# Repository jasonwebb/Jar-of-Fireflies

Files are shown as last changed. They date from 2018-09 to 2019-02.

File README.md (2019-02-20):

---
WARNING: This project is currently being prototyped! Ping me if you'd like to build one and want to know the current status.
---

# Jar of Fireflies

Mason jar outfitted with LEDs and a small microcontroller programmed to mimic the behavior of fireflies caught on a warm summer night. A gentle tap of a button catches the attention of a lights, startling them and causing them to rapidly flash for a moment before returning to their blissful natural state.

An external sensor interface enables more complex interactions using both analog and digital sensors for properties like temperature, sound, light, distance/proximity, movement, tilt, biometrics, and much more.

This is a modernized reinvention of the classic ["Jar of fireflies"](http://www.instructables.com/id/Jar-of-Fireflies/) project by Keso using the Arduino framework and the ATTiny85 microcontroller.

## Features
* ATTiny85 microcontroller programmed with Arduino using the [HLT bootloader](http://hlt.media.mit.edu/?p=1695), mounted in a DIP IC socket for easy removal and replacement.
* Six charlieplexed through-hole LEDs, with the option to use SMD LEDs with fancy soldering.
* Large plated hole pairs for alligator clips so multiple jars can be daisy-chained to a single power source.
* Tactile button to trigger an animation sequence ("dance mode").
* 3-pin interface for external sensors (both analog and digital) to enable more complex interactions.
* 2x3 pin ICSP interface for easier reprogramming.
* Multiple power input options including:
  * 3.5mm center-positive barrel jack for common wall supplies.
  * 2-pin JST-PH jack for battery packs.

## License
This work is licensed under the [Creative Commons BY-NC-SA (Attribution - NonCommercial - ShareAlike) 4.0 International License](http://creativecommons.org/licenses/by-nc-sa/4.0/).



This means that you are completely free to use and modify any of these files for personal and educational use (with a shout-out 🙂), but manufacturing, selling and marketing this project to mass markets for your own profit is prohibited. If this is something that you are interested in doing, please contact me about setting up a partnership!

This license is chosen mainly in an effort, however naive, to discourage low-quality "knock offs" from flooding the market, which can lead to frustration and lack of trust in consumers caused by poor documentation, support, and quality assurance - a concern that tends to be unique to open-source hardware.

I expressly and strongly approve of use of this project for conference badges/swag, soldering workshops, art projects, and other small-scale community and creative-oriented applications. Such applications are what motivate me to share these source files in the first place!

## Designs

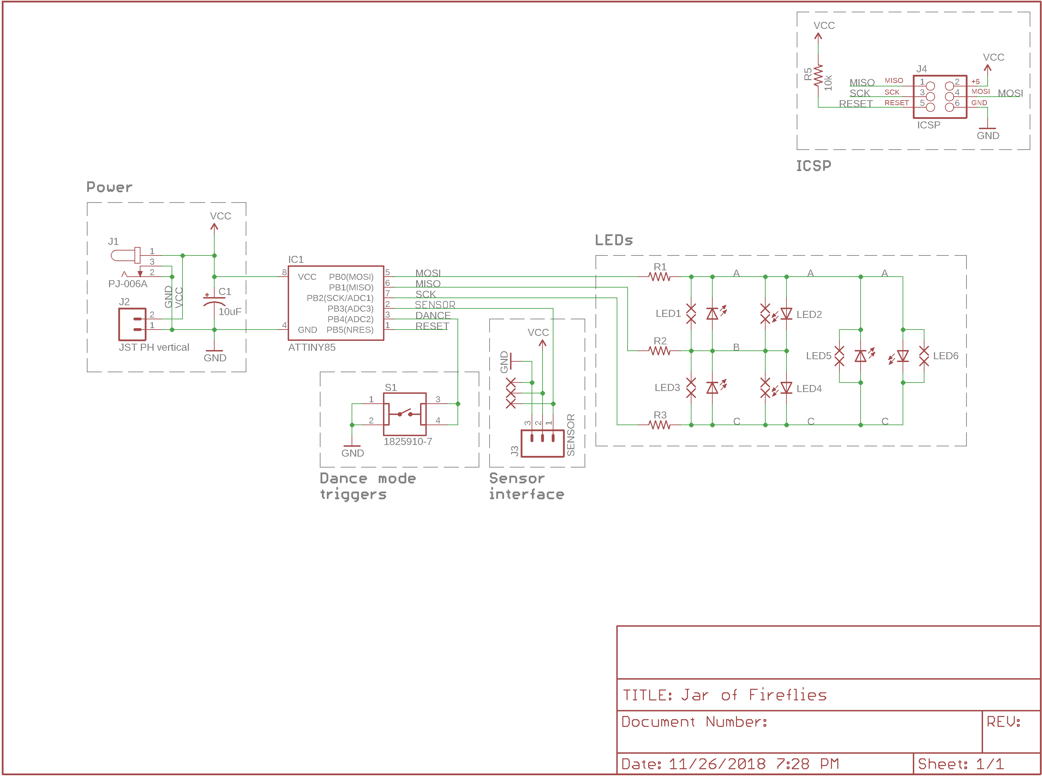
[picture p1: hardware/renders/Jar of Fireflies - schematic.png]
Schematic


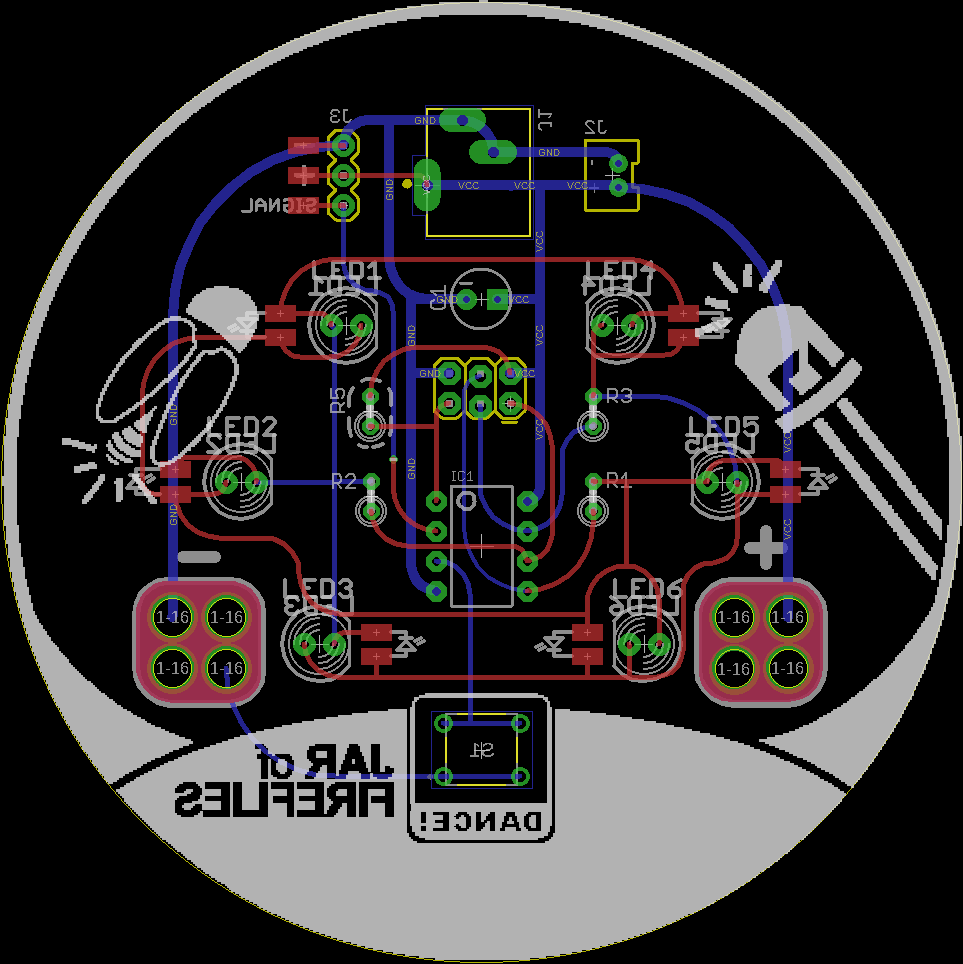
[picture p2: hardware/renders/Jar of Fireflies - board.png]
PCB layout


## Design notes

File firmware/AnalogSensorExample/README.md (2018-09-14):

Examples of sensors:
- [Proximity/distance](https://www.sparkfun.com/categories/84) - thinking of IR rangefinders, but could also work for ultrasonic rangefinders
- [Temperature](https://www.sparkfun.com/categories/82)
- Tilt using mechanical sensor or accelerometer for hands-on manipulation
- [Sound](https://www.sparkfun.com/categories/186)
- [Flex or force](https://www.sparkfun.com/categories/143)
- Biometrics
  - [Muscle activity](https://www.sparkfun.com/products/13723)
- Environmental
  - [Soil moisture](https://www.sparkfun.com/products/13637)
  - [pH level](https://www.sparkfun.com/products/10972)
  - Various gas and chemical sensors ([LPG](https://www.sparkfun.com/products/9405), [particles](https://www.sparkfun.com/products/14045), [dissolved oxygen](https://www.sparkfun.com/products/11194), [more](https://www.sparkfun.com/categories/146)).

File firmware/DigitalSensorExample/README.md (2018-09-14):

Examples of sensors:
- [Sparkfun Capacitive Touch Breakout - AT42QT1011](https://www.sparkfun.com/products/14520)

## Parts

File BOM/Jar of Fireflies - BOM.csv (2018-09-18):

ID | Name | Purpose | Qty | Cost @ 1 | Cost @ 25 | Cost @ 50 | Cost @ 100 | Total @ 1 | Total @ 25 | Total @ 50 | Total @ 100 | Part number | URL
IC1 | ATTINY85-20PU-ND | Microcontroller | 1 | $1.24 | $1.33 | $1.33 | $1.03 | $1.24 | $1.33 | $1.33 | $1.03 | ATTINY85-20PU-ND | https://www.digikey.com/product-detail/en/microchip-technology/ATTINY85-20PU/ATTINY85-20PU-ND/735469
 | 8-pin DIP IC socket | Holds ATTiny85 | 1 | $0.18 | $0.15 | $0.15 | $0.13 | $0.18 | $0.15 | $0.15 | $0.13 | AE9986-ND | https://www.digikey.com/product-detail/en/assmann-wsw-components/A-08-LC-TT/AE9986-ND/821740
C1 | 10uF 50V aluminum capacitor | Power smoothing | 1 | $0.23 | $0.15 | $0.15 | $0.08 | $0.23 | $0.15 | $0.15 | $0.08 | P10425CT-ND | https://www.digikey.com/product-detail/en/panasonic-electronic-components/ECA-1HM100I/P10425CT-ND/8603345
R1-R3 | 150ohm, 1/4W resistor | Current limits for LEDs | 3 | $0.10 | $0.03 | $0.02 | $0.02 | $0.30 | $0.09 | $0.07 | $0.05 | CF14JT150RCT-ND | https://www.digikey.com/product-detail/en/stackpole-electronics-inc/CF14JT150R/CF14JT150RCT-ND/1830603
R4 | 1M, 1/4W resistor | Piezo drain | 1 | $0.10 | $0.03 | $0.02 | $0.02 | $0.10 | $0.03 | $0.02 | $0.02 | CF14JT1M00CT-ND | https://www.digikey.com/product-detail/en/stackpole-electronics-inc/CF14JT1M00/CF14JT1M00CT-ND/1830423
R5 | 10k, 1/4W resistor | Pull-up for ICSP RESET pin | 1 | $0.10 | $0.03 | $0.02 | $0.02 | $0.10 | $0.03 | $0.02 | $0.02 | CF14JT10K0CT-ND | https://www.digikey.com/product-detail/en/stackpole-electronics-inc/CF14JT10K0/CF14JT10K0CT-ND/1830374
LED1-6 | Amber LED, 2.1V @ 20mA, 5mm | Fireflies | 6 | $0.28 | $0.28 | $0.28 | $0.25 | $1.68 | $1.68 | $1.68 | $1.49 | C566C-AFF-CU0W0252CT-ND | https://www.digikey.com/product-detail/en/cree-inc/C566C-AFF-CU0W0252/C566C-AFF-CU0W0252CT-ND/7666543
J1 | 3.5mm DC power jack | Wall and solar power | 1 | $0.78 | $0.65 | $0.62 | $0.59 | $0.78 | $0.65 | $0.62 | $0.59 | CP-006A-ND | https://www.digikey.com/product-detail/en/cui-inc/PJ-006A/CP-006A-ND/269296
J2 | 2-pin JST PH vertical jack | Battery pack input | 1 | $0.17 | $0.16 | $0.16 | $0.10 | $0.17 | $0.16 | $0.16 | $0.10 | 455-1704-ND | https://www.digikey.com/products/en?mpart=B2B-PH-K-S%28LF%29%28SN%29&v=455
J3 | 3-pin 0.1" male header | Sensor interface | 1 | $0.13 | $0.09 | $0.07 | $0.07 | $0.13 | $0.09 | $0.07 | $0.07 | 732-5316-ND | https://www.digikey.com/product-detail/en/wurth-electronics-inc/61300311121/732-5316-ND/4846825
J4 | 2x3-pin 0.1" male header | ICSP interface | 1 |  |  |  |  | $0.00 | $0.00 | $0.00 | $0.00 | Not to be permanently soldered to board - just press-fit into ICSP plug
PIEZO | Piezo element | Trigger for 'dance' mode | 1 | $0.98 | $0.71 | $0.67 | $0.62 | $0.98 | $0.71 | $0.67 | $0.62 | 445-172991-ND | https://www.digikey.com/product-detail/en/tdk-corporation/PS1550L40N/445-172991-ND/5244592
S1 | Momentary switch | Manual trigger for 'dance' mode | 1 | $0.01 | $0.10 | $0.10 | $0.09 | $0.01 | $0.10 | $0.10 | $0.09 | 450-1804-ND | https://www.digikey.com/product-detail/en/te-connectivity-alcoswitch-switches/1825910-7/450-1804-ND/1731414
 |  |  |  |  |  |  | Total | $5.90 | $5.17 | $5.04 | $4.28

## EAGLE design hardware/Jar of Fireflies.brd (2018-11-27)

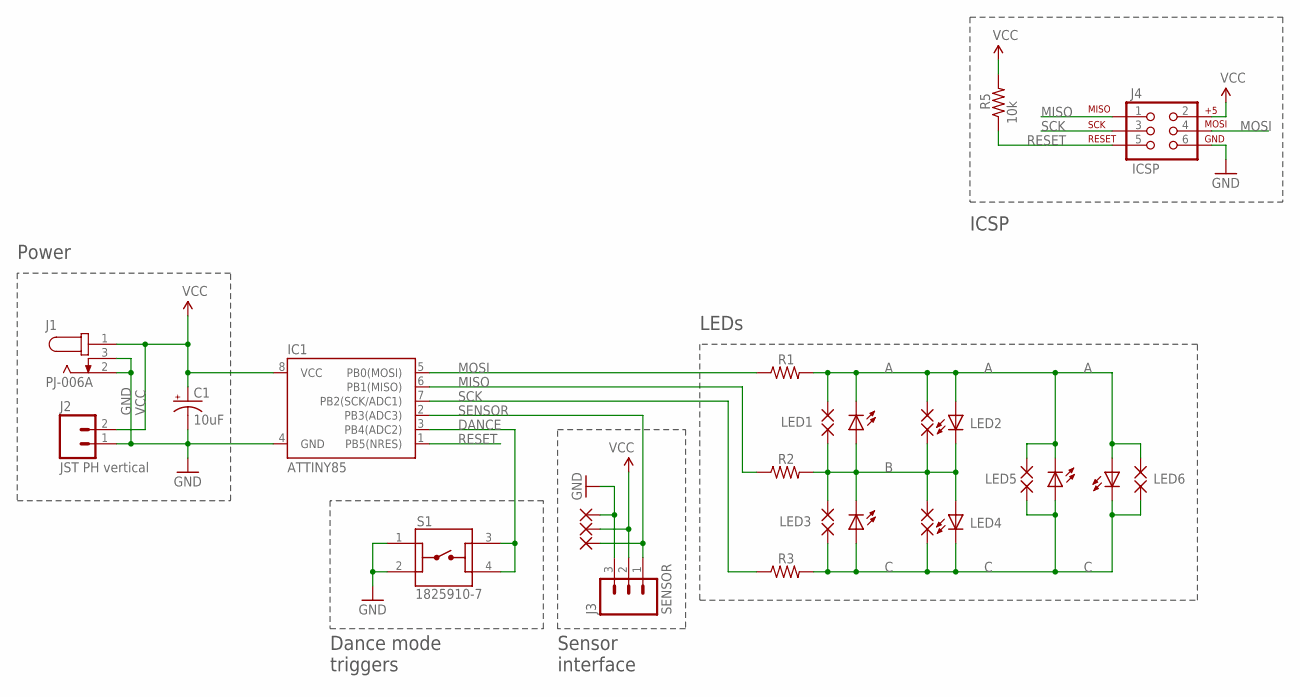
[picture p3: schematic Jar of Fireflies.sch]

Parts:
C1: 10uF; CPOL-RADIAL-10UF-25V
IC1: ATTINY85; DIP08
J1: PJ-006A; CUI_PJ-006A
J2: JST PH vertical; JST-2-PTH-VERT
J3: SENSOR; 1X03
J4: ICSP; 2X3_LOCK
LED1, LED2, LED3, LED4, LED5, LED6: Amber; LED5MM
PAD1, PAD2, PAD3, PAD4, PAD5, PAD6, PAD7, PAD8, PAD9, PAD10, PAD11, PAD12: SMD2; SMD1,27-2,54
PAD13, PAD14, PAD15: WIREPADSMD1,27-254; SMD1,27-2,54
R1, R2, R3: 150; 0207/2V
R5: 10k; 0207/2V
S1: 1825910-7; SW_1825910-7

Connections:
A: LED1.K (C), LED2.A, LED5.K (C), LED6.A, PAD1.1, PAD5.1, PAD9.1, PAD11.1, R1.2
B: LED1.A, LED2.K (C), LED3.K (C), LED4.A, PAD2.1, PAD3.1, PAD6.1, PAD7.1, R2.2
C: LED3.A, LED4.K (C), LED5.A, LED6.K (C), PAD4.1, PAD8.1, PAD10.1, PAD12.1, R3.2
DANCE: IC1.3 (PB4(ADC2)), S1.3, S1.4
GND: C1.2 (-), IC1.4 (GND), J1.2, J1.3, J2.1, J3.3, J4.6, PAD13.1, S1.1, S1.2
MISO: IC1.6 (PB1(MISO)), J4.1, R2.1
MOSI: IC1.5 (PB0(MOSI)), J4.4, R1.1
RESET: IC1.1 (PB5(NRES)), J4.5, R5.1
SCK: IC1.7 (PB2(SCK/ADC1)), J4.3, R3.1
SENSOR: IC1.2 (PB3(ADC3)), J3.1, PAD15.1
VCC: C1.1 (+), IC1.8 (VCC), J1.1, J2.2, J3.2, J4.2, PAD14.1, R5.2

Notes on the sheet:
ICSP
Power
Dance mode triggers
Sensor interface
LEDs

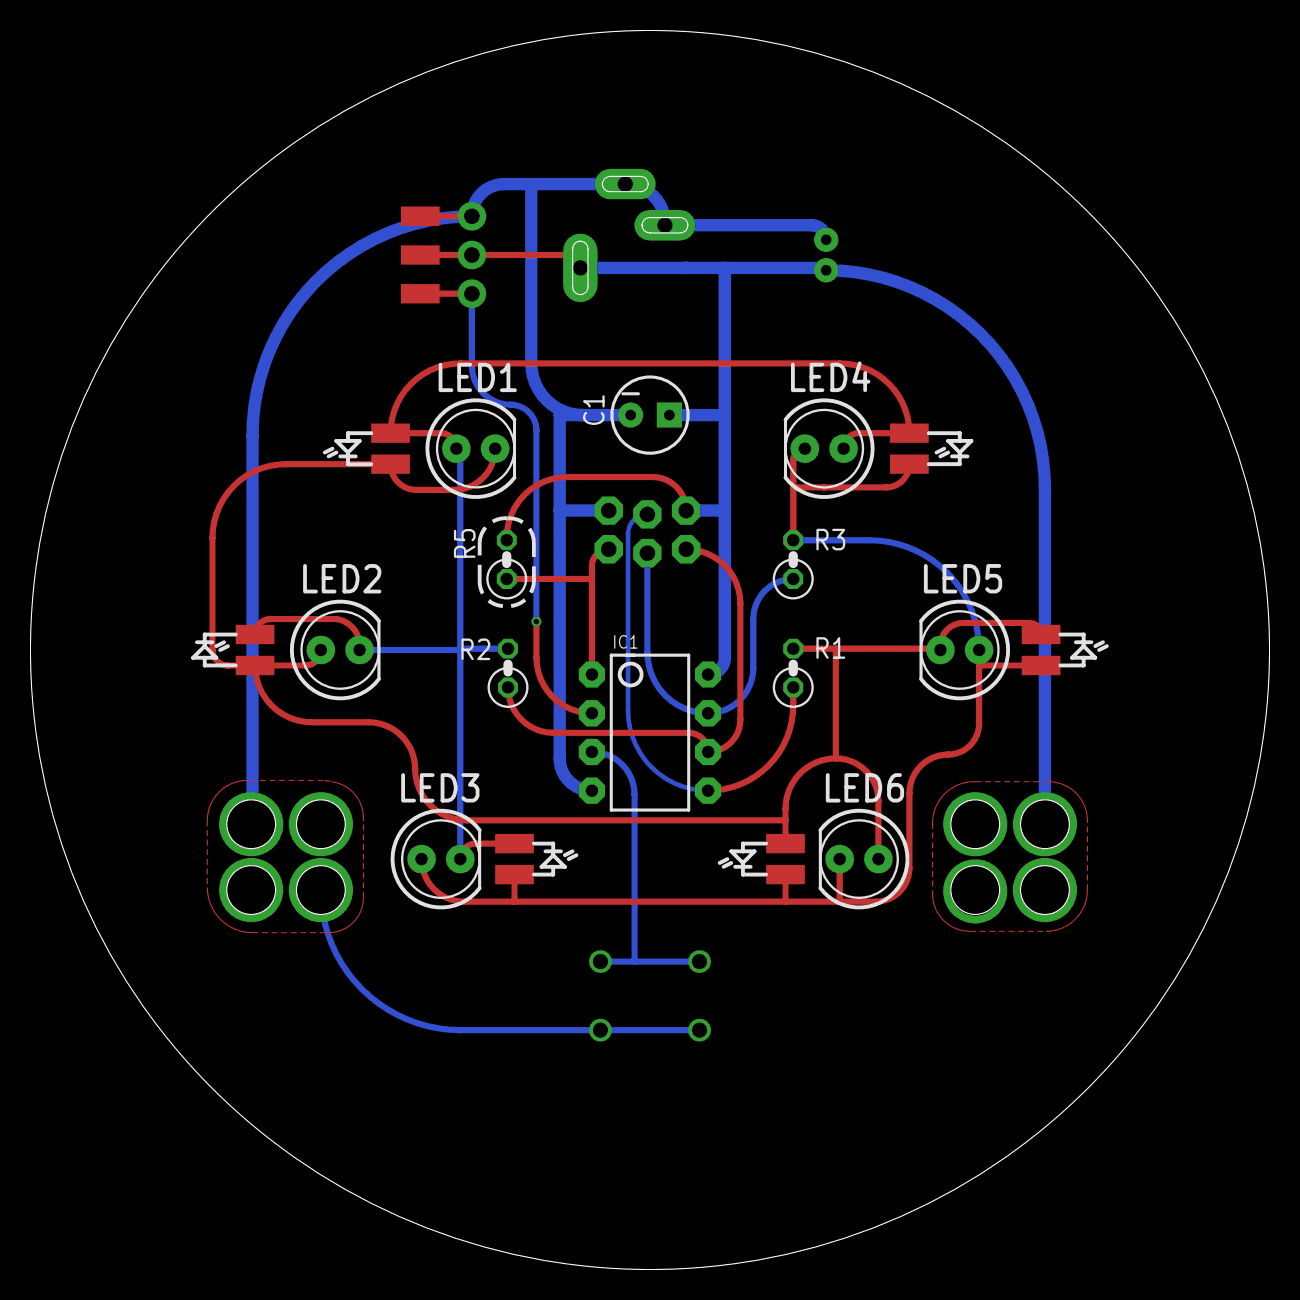
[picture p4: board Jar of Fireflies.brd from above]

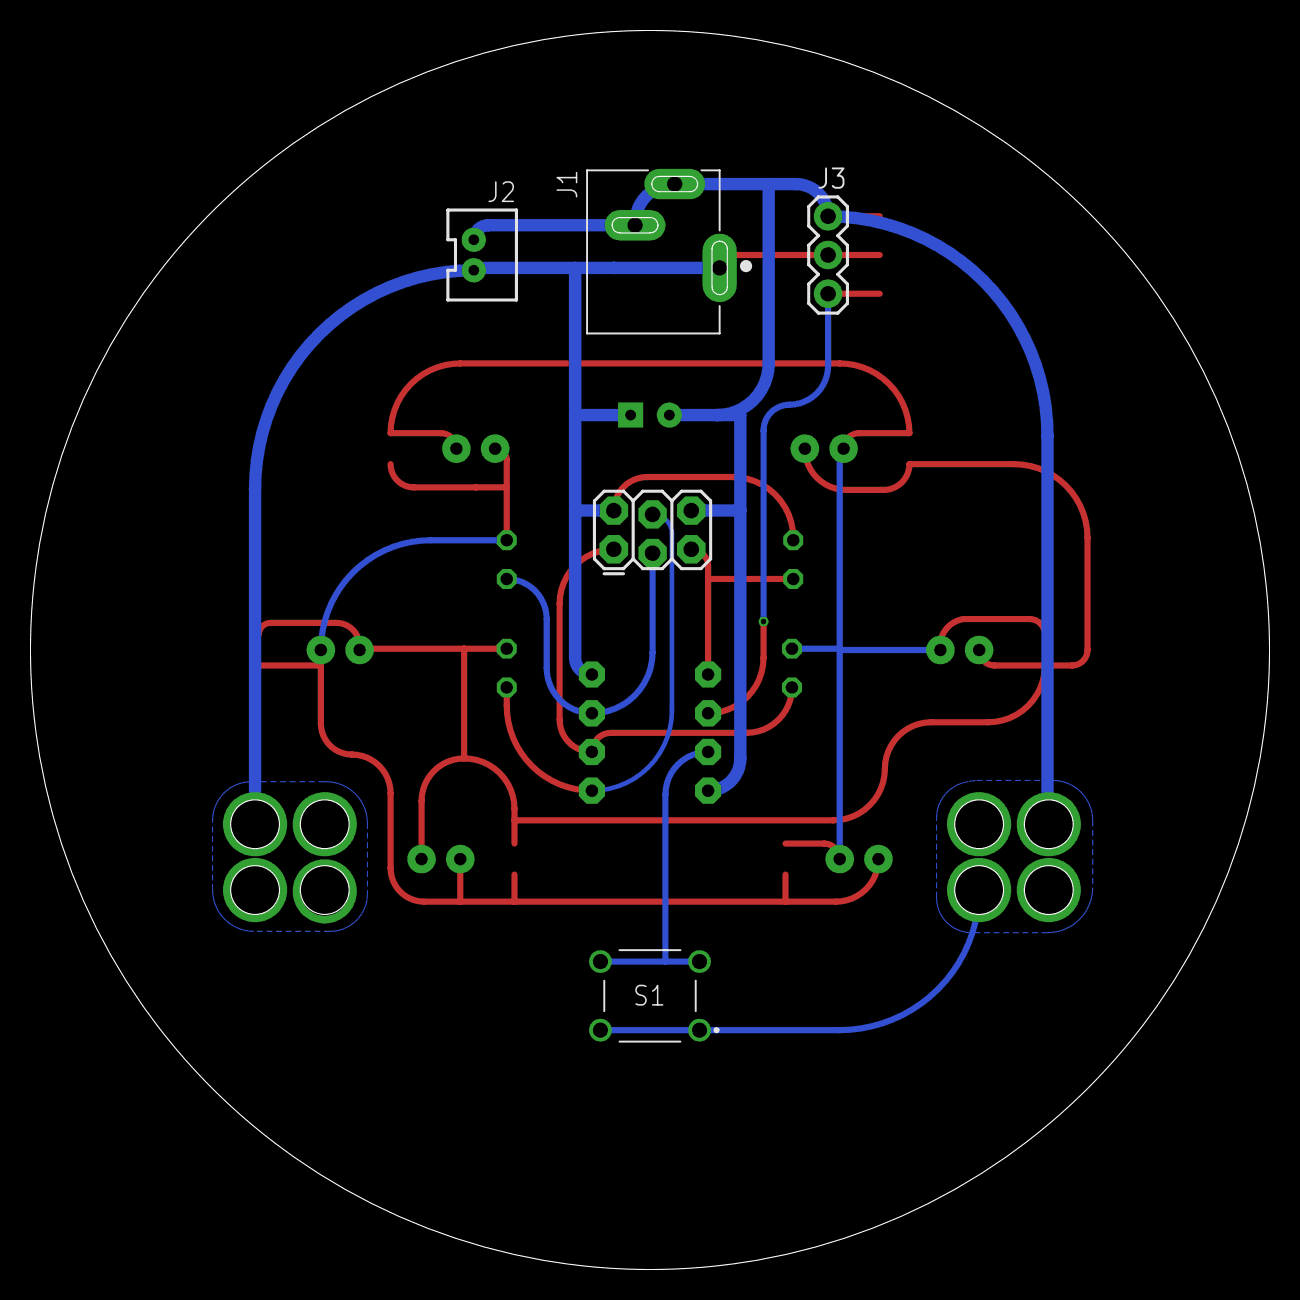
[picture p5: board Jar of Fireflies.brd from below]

Board: 2 copper layers, 81.3 x 81.3 mm, 32 parts (5 on the bottom side), 11 nets.

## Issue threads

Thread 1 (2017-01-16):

Look into adding an on-board ICSP interface

jasonwebb, 2017-01-16:
Currently the ATTiny85 must be removed and programmed using an external programmer such as a USBtiny or an Arduino running ArduinoISP. Not a big deal for the most part, but will be a bottleneck if I ever decide to manufacture kits or need to make a lot for a special project.

I now own a USBtiny programmer, so it makes sense to look into adding a minimal ICSP header to the board that can be optionally used.

jasonwebb, 2018-08-25:
ICSP interface has been added to PCB design.

Closed 2018-08-25.

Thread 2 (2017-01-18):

Add a button to trigger "excited" state

jasonwebb, 2017-01-18:
The piezo is nice, but hard to solder and a bit finicky. Add a footprint for a small tactile switch in parallel with it to allow for alternative triggering.

jasonwebb, 2018-08-25:
Button has been added to PCB design.

Closed 2018-08-25.

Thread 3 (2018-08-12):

Reevaluate input power interfaces based on expected applications

jasonwebb, 2018-08-12:
Right now the board includes a variety of input power interfaces, though they do crowd the board a little bit (especially the DC barrel jack). I wonder if I should drop some based on how I see this board being used. Want to keep enough options to support the most common power interfaces.

**Current options on board**
- 2-pin screw terminal
- 3.5mm DC barrel jack
- 2-pin JST SM socket

**Power options to support**
- Solar panels - seems like a lot of the larger ones come with DC barrel jacks of some kind, but the smaller ones only have solder pads. Need to research and consider how commonly they'd be used.
- Rechargeable battery packs (lion, lipo, etc) - seem to most often come with 2-pin JST plugs
- Alkaline battery packs (AA, AAA, etc) - seems like a lot of them use either a DC barrel plug or a 2-pin JST plug.

Right now it seems like the 2-pin screw terminal is the least useful. They also tend to be finicky to work with, so less experienced users may be frustrated.

The DC barrel jack is relatively bulk, but perhaps necessary. I wonder if there is a more compact vertical mounting style for these?

jasonwebb, 2018-08-12:
Well lookey here - there **are** vertical-mount DC barrel jacks out there! Buying one to test: https://www.digikey.com/product-detail/en/cui-inc/PJ-006A/CP-006A-ND/269296

jasonwebb, 2018-08-25:
The vertical-mount DC jack works great, so I've switched over to using it in the newest PCB design.

I've also removed the 2-pin screw terminal.

Closed 2018-08-25.

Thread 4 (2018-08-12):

Design and prototype an interface for arbitrary sensors

jasonwebb, 2018-08-12:
Pin 2 (PB3/ADC3) of the ATTiny85 is currently unused, which means there is some potential for allow for some experimental interfacing with arbitrary analog sensors (temperature, sound, pressure, etc). Just need to think about how to make it easy - maybe a 3-pin male header?

jasonwebb, 2018-08-25:
A 3-pin, 0.1" male header has been added to the design to provide an easy interface to GND, VCC, and a direct connection to pin 2 (PB3 / ADC3).

Closed 2018-08-25.

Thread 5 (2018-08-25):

Order PCBs and parts for newest board design for prototyping

jasonwebb, 2018-08-25:
Once all the recent board design updates are done, I can go ahead and order a new round of PCBs for prototyping. Just need to refresh my knowledge of board house requirements (and fetch any new CAM presets), generate some Gerber files, and fill out the request. The last time I ordered boards I used SeeedStudio and found the boards to be great quality, low cost, and reasonably fast to fab and ship.

Once the boards are ordered I can also go ahead and order a couple batches of the parts from the [BOM](https://github.com/jasonwebb/Jar-of-Fireflies/blob/master/BOM/Jar%20of%20Fireflies%20-%20BOM.csv).

jasonwebb, 2018-09-04:
10 PCBs (5 green, 5 blue) have been ordered from Seeed Studio! I've also ordered enough parts for 5 kits from DigiKey for prototyping.

Closed 2018-09-13.

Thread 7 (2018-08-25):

Update firmware to work with newest design

jasonwebb, 2018-08-25:
In the new design I have added a couple things that need to be accounted for in the firmware.

Specifically I have added a tactile switch to trigger the "dance mode", as well as a new 3-pin sensor interface.

I'd like to support the new button directly in the core firmware, but I will probably provide additional sketches to demo how to use the 3-pin sensor interface.

jasonwebb, 2018-09-13:
Core firmware updated in commit 514816b3cda32db6acb0ba061eae2aaff982cafb

Closed 2018-09-13.

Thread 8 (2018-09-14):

Create example sketch(es) for external sensors

jasonwebb, 2018-09-14:
I've added a 3-pin interface for connecting to external analog or digital sensors. Usage is pretty simple, but I'd like to provide at least a couple sketches to demonstrate how it could be used.

Sensors to explore include:
- [Proximity/distance](https://www.sparkfun.com/categories/84) - thinking of IR rangefinders, but could also work for ultrasonic rangefinders
- [Temperature](https://www.sparkfun.com/categories/82)
- Tilt using mechanical sensor or accelerometer for hands-on manipulation
- [Sound](https://www.sparkfun.com/categories/186)
- [Touch](https://www.sparkfun.com/categories/117)
- [Flex or force](https://www.sparkfun.com/categories/143)
- Biometrics
  - [Pulse / heart rate](https://www.sparkfun.com/products/11574)
  - [Muscle activity](https://www.sparkfun.com/products/13723)
- Environmental
  - [Soil moisture](https://www.sparkfun.com/products/13637)
  - [pH level](https://www.sparkfun.com/products/10972)
  - Various gas and chemical sensors ([LPG](https://www.sparkfun.com/products/9405), [particles](https://www.sparkfun.com/products/14045), [dissolved oxygen](https://www.sparkfun.com/products/11194), [more](https://www.sparkfun.com/categories/146)).

jasonwebb, 2018-09-14:
Example for simple digital sensors added - https://github.com/jasonwebb/Jar-of-Fireflies/tree/master/firmware/DigitalSensorExample (commit db0fb9b0f0d7d542fda402aa50b147bec2f344ab).

jasonwebb, 2018-09-14:
Example for analog sensors added - https://github.com/jasonwebb/Jar-of-Fireflies/tree/master/firmware/AnalogSensorExample (commit ba47880a6637232c38f7d06e538743938efaf869)

jasonwebb, 2019-02-14:
Will break down into multiple issues.

Closed 2019-02-14.

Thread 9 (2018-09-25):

Assemble and test prototype PCBs

jasonwebb, 2018-09-25:
Now that prototype PCBs have arrived, I need to assemble and test them out. Here is the plan:

- [X] Solder parts to board
- [X] Program ATTiny85 using USBtinyISP
- [ ] Test all features
  - [x] Power options
    - [X] Via ICSP
    - [X] Via DC barrel jack
    - [x] Via 2-pin JST jack
  - [ ] Dance triggers
    - [ ] Piezo
    - [x] Buttons
  - [x] Sensor interface
- [ ] Measure current draw
  - [ ] With all LEDs on full-power.
  - [ ] In normal operation mode.

jasonwebb, 2018-09-26:
I'm finding that the dance triggers (piezo and button) are not working as expected. I'm betting that the 10M pull-down resistor across the piezo is also discharging the VCC signal coming from the button when it's activated. May need to add a diode, or choose one or the other. Will be testing solutions on breadboard in the near future.

jasonwebb, 2019-02-14:
Everything except for the piezo dance trigger seems to work as expected, so I've removed t from the code (d1c1867) and PCB (932612c).

Closed 2019-02-14.

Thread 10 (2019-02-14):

Create variant for ESP8266-based board

jasonwebb, 2019-02-14:
I'd like to be able to build many of these jars and have them intelligently networked together for interesting effects. To do that they will need a more advanced microcontroller with some sort of wireless technology.

The ESP8266 fits the bill, but I'd rather not have to build and test a functioning board around just the bare module myself. Instead I think I'll use the ESP-12e board with NodeMCU.

jasonwebb, 2019-02-19:
I whipped together a quick proof-of-concept schematic and PCB layout to see if it can be done, and it's looking like it can work!

* To reduce costs, I may want to find a way to have multiple jars share a single ESP-12e somehow, maybe through a daughterboard adapter that connects using the existing headers.
* Will need to create a nice silkscreen design for this
* Since the ESP-12e has way more GPIO pins and processing power than the ATTiny85, I may opt to use "smart" LEDs like the WS2812.

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

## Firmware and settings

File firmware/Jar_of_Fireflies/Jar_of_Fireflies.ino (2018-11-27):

/*
  Jar of Fireflies using ATTiny85

  DESCRIPTION:
    An Arduino sketch for the ATTiny85 (using HLT's bootloader)
    that flashes six charlieplexed LEDs to mimic the behavior of
    fireflies. Using a piezo element and tactile button in parallel
    the LED array can react to human interactions.
*/

// Pin assignments
const byte pinA = 0;        // Physical pin 5 (PB0, MOSI, PWM)
const byte pinB = 1;        // Physical pin 6 (PB1, MISO, PWM)
const byte pinC = 2;        // Physical pin 7 (PB2, SCK, ADC1)
const byte danceButtonPin = 4;  // Physical pin 3 (PB4, ADC2)

// LED variables
byte currentLED;        // Number of currently active LED (1-6)
byte previousLED = -1;  // Last LED flashed so we can avoid flashing it twice in a row
byte rampUpSpeed;       // Randomly generated value for fading in LEDs
byte rampDownSpeed;     // Randomly generated value for fading out LEDs
byte numBlinks;         // Randomly generated value for number of times to flash LED whe fully faded in
int brightness;         // Current brightness (0-255) of currently active LED

// "Dance mode" trigger variables
bool currentDanceButtonState = HIGH;
bool previousDanceButtonState = HIGH;
unsigned long lastDebounceTime = 0;
unsigned long debounceInterval = 50;

// Program states
const byte BEGIN = 0;         // Sets up program for a new cycle
const byte RAMP_UP = 1;       // Fades in current LED
const byte BLINKING = 2;      // Blinks the current LED when at full brightness
const byte RAMP_DOWN = 3;     // Fades out the current LED
const byte DANCE = 4;         // Flashes LEDs in fun pattern
byte CURRENT_ACTION = BEGIN;  // Start program off in BEGIN mode

void setup() {
  pinMode(danceButtonPin, INPUT);      // Make button pin an INPUT
  digitalWrite(danceButtonPin, HIGH);  // Activate internal pullup

  turnOffAll();  // Flush any stray current from the ports
}

void loop() {
  switch (CURRENT_ACTION) {

    // BEGIN ===========================================
    // Set up all the variables to flash a new LED
    case BEGIN:
      // Choose a new LED
      previousLED = currentLED;

      // Make sure it's different than the last one
      do {
        currentLED = (int) random(1, 6);
      } while (currentLED == previousLED);

      // Randomize the number of times to blink
      numBlinks = (int) random(1, 6);

      // Randomize the fade in and fade out speeds
      rampUpSpeed = random(6);
      rampDownSpeed = rampUpSpeed * 2;

      brightness = 0;
      CURRENT_ACTION = RAMP_UP;
      break;

    // RAMP UP ========================================
    // Fade in the LED
    case RAMP_UP:
      analogOn(currentLED, brightness);
      delay(rampUpSpeed);

      if (brightness >= 255) {
        CURRENT_ACTION = BLINKING;
        brightness = 0;
      } else {
        brightness++;
      }

      break;

    // BLINKING ====================================
    // Blink the LED a certain number of times
    case BLINKING:
      analogOn(currentLED, 0);
      delay(random(10, 50));
      analogOn(currentLED, 255);
      delay(random(30, 100));

      if (numBlinks > 0) {
        numBlinks--;
      } else {
        CURRENT_ACTION = RAMP_DOWN;
        brightness = 255;
      }

      break;

    // RAMP DOWN ===========================================
    // Fade out the LED
    case RAMP_DOWN:
      analogOn(currentLED, brightness);
      delay(rampDownSpeed);

      if (brightness == 0) {
        CURRENT_ACTION = BEGIN;
      } else {
        brightness--;
      }

      break;

    // DANCE ==============================================
    // Flash each LED, one at a time, six times in a row
    case DANCE:
      for (int j = 0; j < 6; j++) {
        for (int i = 1; i <= 6; i++) {
          turnOn(i);
          delay(50);
          turnOff(i);
          delay(50);
        }
      }

      CURRENT_ACTION = BEGIN;

      break;
  }

  // Check if there has been any activity on the "dance" button
  checkDanceButton();
}

// Turn on a single LED to full brightness
void turnOn(byte led) {
  analogOn(led, 255);
}

// Turn off an LED completely
void turnOff(byte led) {
  analogOn(led, 0);
}

// Turn off all LEDs and drain any remaining current
void turnOffAll() {
  for (int i = 0; i <= 2; i++) {
    pinMode(i, OUTPUT);
    digitalWrite(i, LOW);
  }
}

// Write an analog value to an LED
void analogOn(byte led, byte value) {
  switch (led) {
    case 1:
      pinMode(pinA, OUTPUT);
      pinMode(pinB, OUTPUT);
      pinMode(pinC, INPUT);

      digitalWrite(pinA, LOW);
      analogWrite(pinB, value);
      break;
    case 2:
      pinMode(pinA, OUTPUT);
      pinMode(pinB, OUTPUT);
      pinMode(pinC, INPUT);

      digitalWrite(pinB, LOW);
      analogWrite(pinA, value);
      break;
    case 3:
      pinMode(pinA, INPUT);
      pinMode(pinB, OUTPUT);
      pinMode(pinC, OUTPUT);

      digitalWrite(pinC, HIGH);
      analogWrite(pinB, 255 - value);
      break;
    case 4:
      pinMode(pinA, INPUT);
      pinMode(pinB, OUTPUT);
      pinMode(pinC, OUTPUT);

      digitalWrite(pinC, LOW);
      analogWrite(pinB, value);
      break;
    case 5:
      pinMode(pinA, OUTPUT);
      pinMode(pinB, INPUT);
      pinMode(pinC, OUTPUT);

      digitalWrite(pinC, HIGH);
      analogWrite(pinA, 255 - value);
      break;
    case 6:
      pinMode(pinA, OUTPUT);
      pinMode(pinB, INPUT);
      pinMode(pinC, OUTPUT);

      digitalWrite(pinC, LOW);
      analogWrite(pinA, value);
      break;
  }
}

// Check if the "dance" button is pressed
void checkDanceButton() {
  // Reduce noise caused by button chatter by only polling periodically
  if(lastDebounceTime + debounceInterval <= millis()) {
    currentDanceButtonState = digitalRead(danceButtonPin);

    // Change of button state detected
    if(currentDanceButtonState != previousDanceButtonState) {
      previousDanceButtonState = currentDanceButtonState;

      // When button is pressed, hijack main loop to enter "dance" mode
      if(currentDanceButtonState == LOW) {
        CURRENT_ACTION = DANCE;
      }
    }

    lastDebounceTime = millis();
  }
}

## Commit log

2012-02-25 First commit of Eagle files
    [Jar_of_Fireflies.brd, Jar_of_Fireflies.sch]
2012-02-27 Updated folder name
    [Jar_of_Fireflies.brd, Jar_of_Fireflies.sch]
2012-02-27 Removing old Eagle folder
    [Jar_of_Fireflies.brd, Jar_of_Fireflies.sch]
2012-12-19 Overdue updates
    [DC-power-adapter.brd, DC-power-adapter.sch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]
2013-01-01 Added BOMs
    [Jar of Fireflies - 2xAA batteries BOM.xlsx, Jar of Fireflies - DC power adapter BOM.xlsx, Jar of Fireflies - USB power adapter BOM.xlsx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]
2014-02-08 Added Arduino sketch
2014-03-01 Updated BOM and Eagle files for rev B
    [DC-power-adapter.brd, DC-power-adapter.sch, Jar of Fireflies (rev B) - BOM.xlsx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]
2014-03-01 Added images of schematic + PCB design
2015-06-26 Updated Eagle files
    Better silkscreen, more power options.
    [Jar of Fireflies (rev B).brd, Jar of Fireflies (rev B).sch]
2017-01-15 Updated folder and file names
    [Jar of Fireflies - bill of materials.csv, Jar of Fireflies - bill of materials.xlsx, Jar of Fireflies.brd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]
2018-08-24 Updating PCB design with ICSP, SMD pads for LEDs, sensor interface, and different power options
    [Jar of Fireflies.brd, Jar of Fireflies.sch]
2018-08-24 Updating references to PCB renders
2018-08-28 Switching to vertical JST jack
    [Jar of Fireflies.brd, Jar of Fireflies.sch]
2018-08-31 Replacing pushbutton with sourced one
    [Jar of Fireflies.brd, Jar of Fireflies.sch]
2018-08-31 Updating BOM with components for newest design
    [Jar of Fireflies - BOM.csv, Jar of Fireflies - bill of materials.csv, Jar of Fireflies - bill of materials.xlsx]
2018-09-04 Flipping bitmap silkscreen
    [Jar of Fireflies.brd]
2018-09-08 Abstracting piezo trigger to account for tactile button, improing comments
2018-09-14 Adding sketch example for simple external digital sensors.
2018-09-14 Adding generic example of external analog sensor
2018-09-18 Adding missing part (R5) to BOM
    [Jar of Fireflies - BOM.csv]
2018-11-27 Refactoring dance mode away from piezo to use button only
2018-11-27 Removing piezo from PCB, making button switch to GND, adding solder pads to sensor interface
    [Jar of Fireflies.brd, Jar of Fireflies.sch]
2018-11-27 Documenting dance button setup code
2018-11-27 Adding circuit renders to main README
2019-02-20 Removing references to built-in piezo sensor that is now removed

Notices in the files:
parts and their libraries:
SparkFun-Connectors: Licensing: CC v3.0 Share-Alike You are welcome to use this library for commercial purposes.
